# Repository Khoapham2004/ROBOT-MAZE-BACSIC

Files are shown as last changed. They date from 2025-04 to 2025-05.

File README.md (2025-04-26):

# ROBOT-MAZE-BACSIC
design in kicad : 
Arduino nano, HC-SR04, N20, Driver TB6612FNG, MPU, LM2596, Botton

 




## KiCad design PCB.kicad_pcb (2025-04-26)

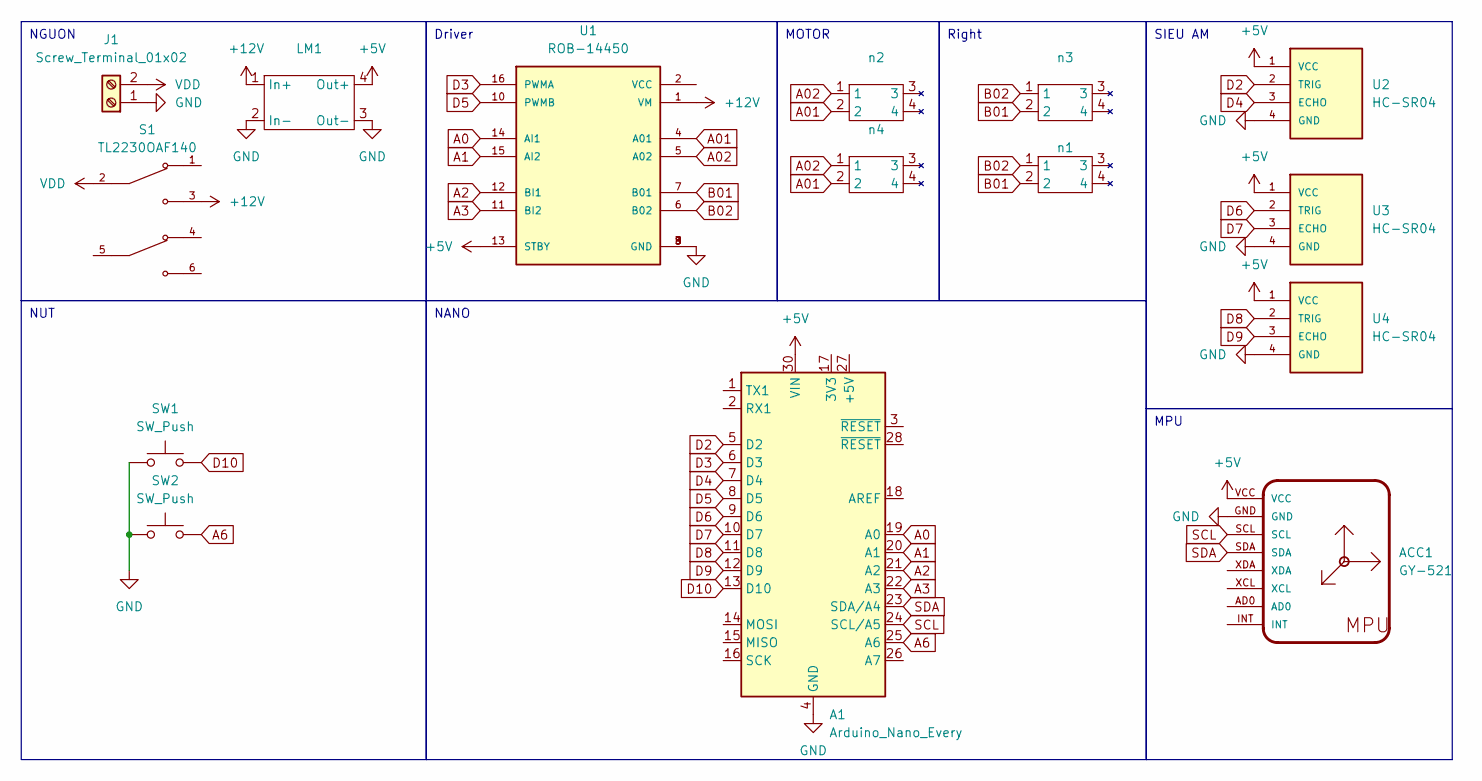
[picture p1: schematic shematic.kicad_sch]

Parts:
A1: Arduino_Nano_Every; Arduino_Nano
ACC1: GY-521
J1: Screw_Terminal_01x02; TerminalBlock_Phoenix_MKDS-1,5-2_1x02_P5.00mm_Horizontal
LM1: Lm2596
S1: TL2230OAF140; SW_6 pins 8.5×8.5MM; PARTREV E
SW1, SW2: SW_Push; SW_PUSH_6mm_H9.5mm
U1: ROB-14450; MODULE_ROB-14450; PARTREV 11-13-17
U2, U3, U4: HC-SR04; XCVR_HC-SR04
n1, n2, n3, n4: n20

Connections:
+5V: A1.30 (VIN), ACC1.VCC, LM1.4 (Out+), U1.13 (STBY), U2.1 (VCC), U3.1 (VCC), U4.1 (VCC)
+12V: LM1.1 (In+), S1.3, U1.1 (VM)
A0: A1.19 (A0), U1.14 (AI1)
A1: A1.20 (A1), U1.15 (AI2)
A01: U1.4 (A01), n2.2, n4.2
A2: A1.21 (A2), U1.12 (BI1)
A02: U1.5 (A02), n2.1, n4.1
A3: A1.22 (A3), U1.11 (BI2)
A6: A1.25 (A6), SW2.2
B01: U1.7 (B01), n1.2, n3.2
B02: U1.6 (B02), n1.1, n3.1
D2: A1.5 (D2), U2.2 (TRIG)
D3: A1.6 (D3), U1.16 (PWMA)
D4: A1.7 (D4), U2.3 (ECHO)
D5: A1.8 (D5), U1.10 (PWMB)
D6: A1.9 (D6), U3.2 (TRIG)
D7: A1.10 (D7), U3.3 (ECHO)
D8: A1.11 (D8), U4.2 (TRIG)
D9: A1.12 (D9), U4.3 (ECHO)
D10: A1.13 (D10), SW1.2
GND: A1.4 (GND), A1.29 (GND), ACC1.GND, J1.1, LM1.2 (In-), LM1.3 (Out-), SW1.1, SW2.1, U1.3 (GND), U1.8 (GND), U1.9 (GND), U2.4 (GND), U3.4 (GND), U4.4 (GND)
SCL: A1.24 (SCL/A5), ACC1.SCL
SDA: A1.23 (SDA/A4), ACC1.SDA
VDD: J1.2, S1.2

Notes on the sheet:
NGUON
NUT
SIEU AM
MPU
Right
NANO
MOTOR
Driver

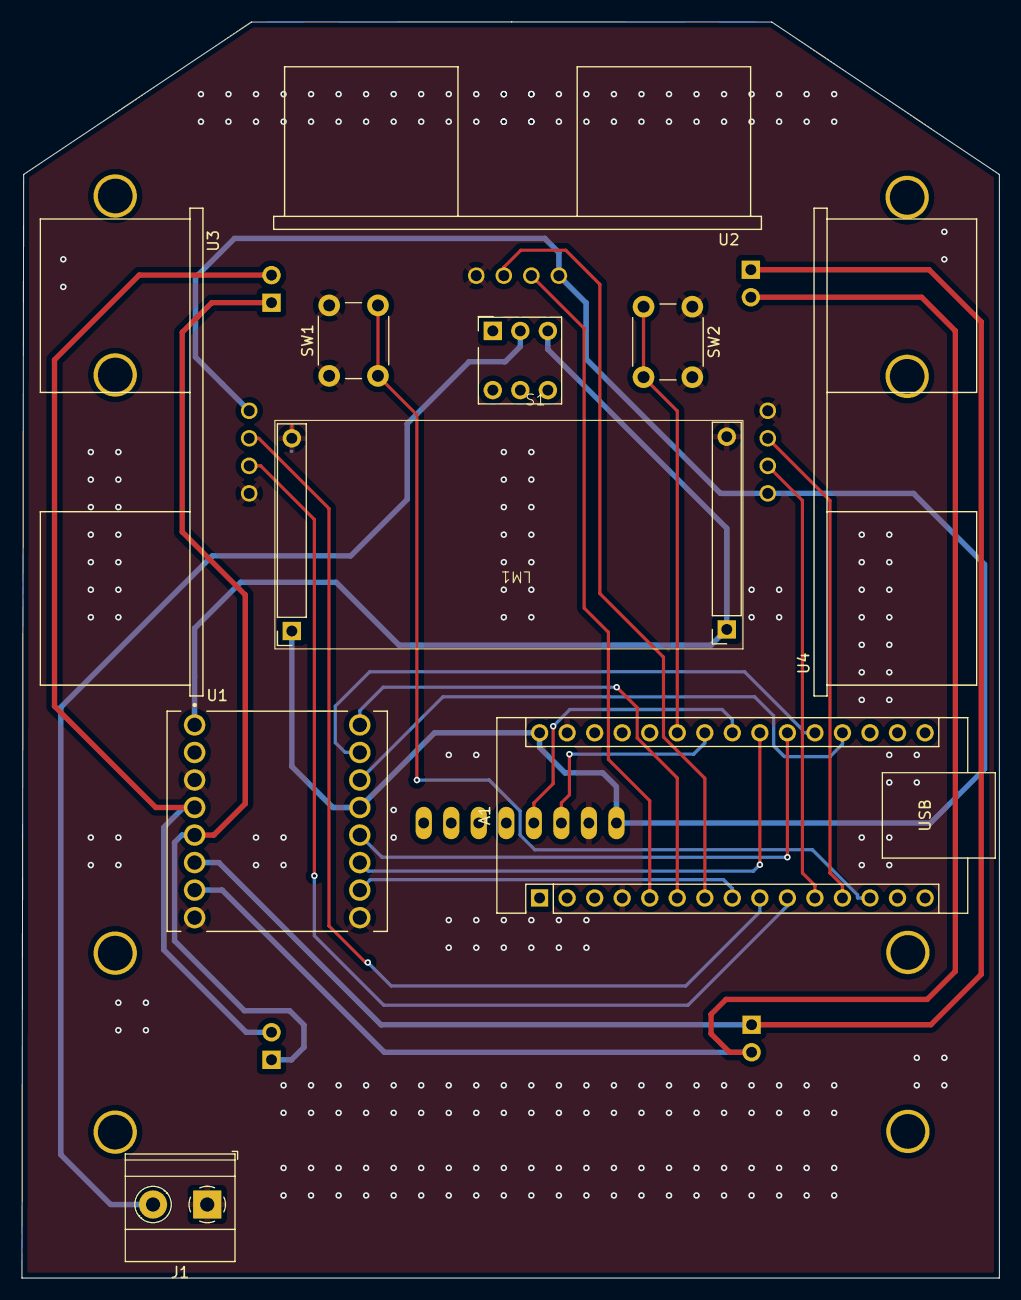
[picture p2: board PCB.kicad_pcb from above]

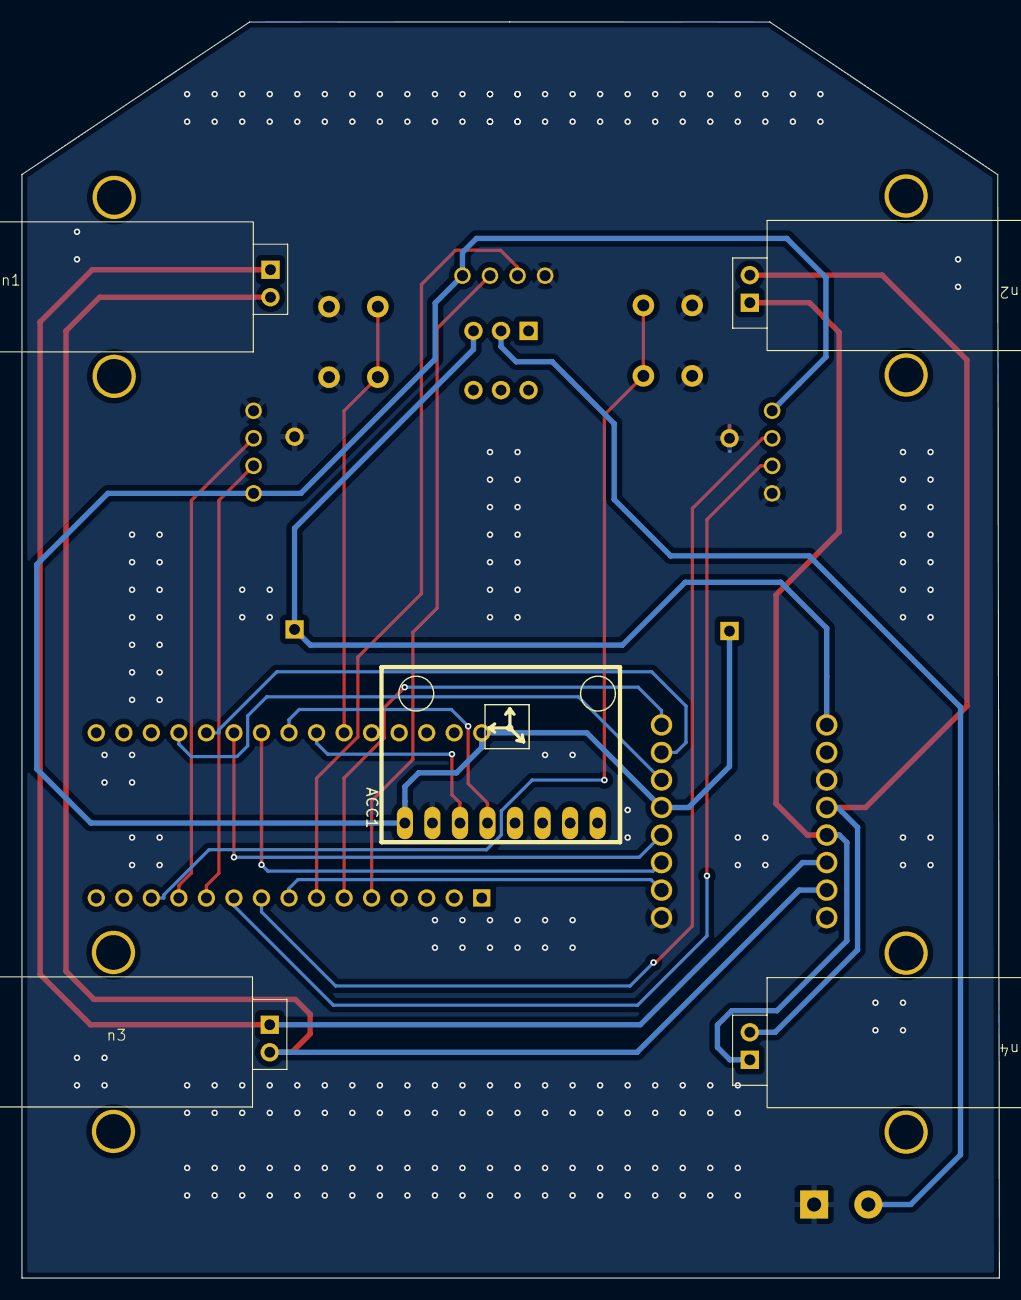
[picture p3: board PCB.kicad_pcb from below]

Board: 2 copper layers, 90.2 x 115.9 mm, 15 parts (5 on the bottom side), 24 nets.

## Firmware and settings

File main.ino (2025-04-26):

#include <Wire.h>
#include <MPU6050.h>

MPU6050 mpu;

// Cảm biến siêu âm
int trig1 = 6, echo1 = 7;
int trig2 = 2, echo2 = 4;
int trig3 = 8, echo3 = 9;

#define buttonR 10
#define buttonL A6
// Motor driver
#define AIN1 A0
#define AIN2 A1
#define PWMA 3
#define BIN1 A2
#define BIN2 A3
#define PWMB 5

// Ngưỡng & tốc độ
float speedSound = 0.0343;
int DIS = 15;
int speed = 100;

// Khoảng cách đo được
long leftDistance, middleDistance, rightDistance;

// Biến yaw
float yaw = 0;
unsigned long lastTime;

// Đọc khoảng cách siêu âm
long measureDistance(int trig, int echo) {
  digitalWrite(trig, LOW);
  delayMicroseconds(2);
  digitalWrite(trig, HIGH);
  delayMicroseconds(10);
  digitalWrite(trig, LOW);
  return (pulseIn(echo, HIGH) / 2.0) * speedSound;
}

// Cập nhật yaw bằng tích phân gyroZ
void updateYaw() {
  int16_t gx, gy, gz, ax, ay, az;
  mpu.getMotion6(&ax, &ay, &az, &gx, &gy, &gz);
  unsigned long now = millis();
  float dt = (now - lastTime) / 1000.0;
  lastTime = now;
  float gyroZ = gz / 131.0;      // độ/giây
  yaw += gyroZ * dt;            // tích phân thành góc
}

// Quay trái chính xác 90°
void turnLeft90() {
  updateYaw();
  float start = yaw;
  // bắt đầu quay trái
  digitalWrite(AIN1, LOW); digitalWrite(AIN2, HIGH);
  digitalWrite(BIN1, LOW); digitalWrite(BIN2, HIGH);
  analogWrite(PWMA, speed);
  analogWrite(PWMB, speed);
  // quay cho đến khi đạt ~90°
  while (abs(yaw - start) < 85) {
    updateYaw();
  }
  // dừng
  analogWrite(PWMA, 0);
  analogWrite(PWMB, 0);
  delay(200);
}

// Quay phải chính xác 90°
void turnRight90() {
  updateYaw();
  float start = yaw;
  // bắt đầu quay phải
  digitalWrite(AIN1, HIGH); digitalWrite(AIN2, LOW);
  digitalWrite(BIN1, HIGH); digitalWrite(BIN2, LOW);
  analogWrite(PWMA, speed);
  analogWrite(PWMB, speed);
  // quay cho đến khi đạt ~90°
  while (abs(yaw - start) < 85) {
    updateYaw();
  }
  // dừng
  analogWrite(PWMA, 0);
  analogWrite(PWMB, 0);
  delay(200);
}
// Quay phải chính xác 90°
void turnRight180() {
  updateYaw();
  float start = yaw;
  // bắt đầu quay phải
  digitalWrite(AIN1, HIGH); digitalWrite(AIN2, LOW);
  digitalWrite(BIN1, HIGH); digitalWrite(BIN2, LOW);
  analogWrite(PWMA, speed);
  analogWrite(PWMB, speed);
  // quay cho đến khi đạt ~90°
  while (abs(yaw - start) < 180) {
    updateYaw();
  }
  // dừng
  analogWrite(PWMA, 0);
  analogWrite(PWMB, 0);
  delay(200);
}

// Di chuyển tiến thẳng
void moveForward() {
  digitalWrite(AIN1, HIGH); digitalWrite(AIN2, LOW);
  digitalWrite(BIN1, LOW);  digitalWrite(BIN2, HIGH);
  analogWrite(PWMA, speed);
  analogWrite(PWMB, speed);
}

// Dừng
void moveStop() {
  digitalWrite(AIN1, LOW); digitalWrite(AIN2, LOW);
  digitalWrite(BIN1, LOW); digitalWrite(BIN2, LOW);
  analogWrite(PWMA, 0);
  analogWrite(PWMB, 0);
}

// Điều chỉnh song song tường phải
void moveForwardR() {
  long r = measureDistance(trig3, echo3);
  if (r < 6)        analogWrite(PWMB, speed), analogWrite(PWMA, speed/2);
  else if (r > 7)   analogWrite(PWMA, speed), analogWrite(PWMB, speed/2);
  else              analogWrite(PWMA, speed), analogWrite(PWMB, speed);
  digitalWrite(AIN1, HIGH); digitalWrite(AIN2, LOW);
  digitalWrite(BIN1, LOW);  digitalWrite(BIN2, HIGH);
}

// Điều chỉnh song song tường trái
void moveForwardL() {
  long l = measureDistance(trig1, echo1);
  if (l < 7)        analogWrite(PWMB, speed/2), analogWrite(PWMA, speed);
  else if (l > 8)   analogWrite(PWMA, speed/2), analogWrite(PWMB, speed);
  else              analogWrite(PWMA, speed),   analogWrite(PWMB, speed);
  digitalWrite(AIN1, HIGH); digitalWrite(AIN2, LOW);
  digitalWrite(BIN1, LOW);  digitalWrite(BIN2, HIGH);
}

void setup() {
  Serial.begin(9600);
  Wire.begin();
  mpu.initialize();
  if (!mpu.testConnection()) {
    Serial.println("MPU6050 lỗi kết nối!");
    while (1);
  }
  lastTime = millis();
  yaw = 0; // reset góc ban đầu
  pinMode(buttonR, INPUT_PULLUP);   // Chân D10 dùng kéo trở trong
  pinMode(buttonL, INPUT_PULLUP);    // Chân A6 cũng dùng kéo trở trong
  // khởi tạo siêu âm
  pinMode(trig1, OUTPUT); pinMode(echo1, INPUT);
  pinMode(trig2, OUTPUT); pinMode(echo2, INPUT);
  pinMode(trig3, OUTPUT); pinMode(echo3, INPUT);

  // khởi tạo motor
  pinMode(AIN1, OUTPUT); pinMode(AIN2, OUTPUT); pinMode(PWMA, OUTPUT);
  pinMode(BIN1, OUTPUT); pinMode(BIN2, OUTPUT); pinMode(PWMB, OUTPUT);

  moveStop();
}

void loop() {
  moveStop();
  delay(10);

  // Chờ 2 cảm biến trái+phải <20 mới bắt đầu
  while (true) {
    leftDistance  = measureDistance(trig1, echo1);
    rightDistance = measureDistance(trig3, echo3);
    if (leftDistance < 25 && rightDistance < 25) break;
    delay(200);
  }

  // Vòng chạy chính
  while (true) {
    // cập nhật yaw liên tục
    updateYaw();

    // đo khoảng cách
    leftDistance   = measureDistance(trig1, echo1);    delay(10);
    middleDistance = measureDistance(trig2, echo2);    delay(10);
    rightDistance  = measureDistance(trig3, echo3);    delay(10);

    Serial.print("L:"); Serial.print(leftDistance);
    Serial.print(" M:"); Serial.print(middleDistance);
    Serial.print(" R:"); Serial.println(rightDistance);

    if (leftDistance < DIS && middleDistance > DIS && rightDistance < DIS) {
      // đi thẳng + tự chỉnh                               
      moveForward();
      if (leftDistance < rightDistance && leftDistance < 8) {
        analogWrite(PWMA, 100); analogWrite(PWMB, 80);
      } else if (rightDistance < leftDistance && rightDistance < 8) {
        analogWrite(PWMA, 80); analogWrite(PWMB, 100);
      }
    }
    else if (leftDistance > DIS && middleDistance > DIS && rightDistance < DIS) {
      moveForwardR();
    }
    else if (leftDistance < DIS && middleDistance > DIS && rightDistance > DIS) {
      moveForwardL();
    }
    else if (leftDistance > DIS && middleDistance < DIS && rightDistance > DIS) {
      // quẹo phải 90°
      moveForward(); delay(300);
      moveStop();    delay(200);
      turnRight90();
      moveForward();
    }
    else if (leftDistance > DIS && middleDistance < DIS && rightDistance < DIS) {
      // quẹo trái 90°
      moveForward(); delay(300);
      moveStop();    delay(200);
      turnLeft90();
      moveForward();
    }
    else if (leftDistance < DIS && middleDistance < DIS && rightDistance > DIS) {
      // quẹo phải 90°
      moveForward(); delay(300);
      moveStop();    delay(200);
      turnRight90();
      moveForward();
    }
    else if (leftDistance < DIS && middleDistance < DIS && rightDistance < DIS) {
      // chặn 3 phía → dừng và quẹo trái 90°
      moveStop();
      turnRight180();
    }

    delay(10);
  }
}

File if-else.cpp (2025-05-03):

#include <Wire.h>
#include <MPU6050.h>

MPU6050 mpu;
bool justTurned180 = false;

// Cảm biến siêu âm
int trig1 = 6, echo1 = 7; 
int trig2 = 2, echo2 = 4;
int trig3 = 8, echo3 = 9;

#define BTN_LEFT 10  // D10: nút chọn bám trái
#define BTN_RIGHT A6   // A6: nút chọn bám phải
int mode = 0;         // 0: chưa chọn, 1: bám trái, 2: bám phải

// Motor driver
#define AIN1 A0
#define AIN2 A1
#define PWMA 3
#define BIN1 A2
#define BIN2 A3
#define PWMB 5

float speedSound = 0.0343;
int DIS = 10;///////////////////////////
int speed = 100;////////////////////////

long leftDistance, middleDistance, rightDistance;
float yaw = 0;
unsigned long lastTime;

// Đọc khoảng cách
long measureDistance(int trig, int echo) {
  digitalWrite(trig, LOW);
  delayMicroseconds(2);
  digitalWrite(trig, HIGH);
  delayMicroseconds(10);
  digitalWrite(trig, LOW);
  return (pulseIn(echo, HIGH) / 2.0) * speedSound;
}
// Dừng
void moveStop() {
  digitalWrite(AIN1, LOW); digitalWrite(AIN2, LOW);
  digitalWrite(BIN1, LOW); digitalWrite(BIN2, LOW);
  analogWrite(PWMA, 0); analogWrite(PWMB, 0);
}
// Cập nhật góc
void updateYaw() {
  int16_t gx, gy, gz, ax, ay, az;
  mpu.getMotion6(&ax, &ay, &az, &gx, &gy, &gz);
  unsigned long now = millis();
  float dt = (now - lastTime) / 1000.0;
  lastTime = now;
  yaw += (gz / 131.0) * dt;
}

// Quay trái 90°
void turnLeft90() {
  updateYaw();
  float start = yaw;
  digitalWrite(AIN1, HIGH); digitalWrite(AIN2, LOW);
  digitalWrite(BIN1, LOW);  digitalWrite(BIN2, HIGH);
  analogWrite(PWMA, speed);
  analogWrite(PWMB, speed);
  while (abs(yaw - start) < 80) updateYaw();//////////////////////////////
  moveStop(); delay(200);
}

// Quay phải 90°
void turnRight90() {
  updateYaw();
  float start = yaw;
  digitalWrite(AIN1, LOW); digitalWrite(AIN2, HIGH);
  digitalWrite(BIN1, HIGH); digitalWrite(BIN2, LOW);
  analogWrite(PWMA, speed);
  analogWrite(PWMB, speed);
  while (abs(yaw - start) < 80) updateYaw();////////////////////////////////
  moveStop(); delay(200);
}
// Quay phải 90°
void turnRight180() {
  updateYaw();
  float start = yaw;
  digitalWrite(AIN1, LOW); digitalWrite(AIN2, HIGH);
  digitalWrite(BIN1, HIGH); digitalWrite(BIN2, LOW);
  analogWrite(PWMA, speed);
  analogWrite(PWMB, speed);
  while (abs(yaw - start) < 170) updateYaw();////////////////////////////////
  moveStop(); delay(200);
}

// Di chuyển thẳng
void moveForward() {
  digitalWrite(AIN1, LOW); digitalWrite(AIN2, HIGH);
  analogWrite(PWMA, speed);
  digitalWrite(BIN1, LOW); digitalWrite(BIN2, HIGH);
  analogWrite(PWMB, speed);
}

// Bám tường phải
void moveForwardR() {
long r = measureDistance(trig3, echo3);
if (r < 7) {
  analogWrite(PWMA, speed / 2); analogWrite(PWMB, speed);
} else if (r > 8) {
  analogWrite(PWMA, speed); analogWrite(PWMB, speed / 2);
} else {
  analogWrite(PWMA, speed); analogWrite(PWMB, speed);
}
digitalWrite(AIN1, LOW); digitalWrite(AIN2, HIGH);
digitalWrite(BIN1, LOW); digitalWrite(BIN2, HIGH);
}

// Bám tường trái
void moveForwardL() {
long l = measureDistance(trig1, echo1);
if (l < 7) {
  analogWrite(PWMA, speed); analogWrite(PWMB, speed / 2);
} else if (l > 8) {
  analogWrite(PWMA, speed / 2); analogWrite(PWMB, speed);
} else {
  analogWrite(PWMA, speed); analogWrite(PWMB, speed);
}
digitalWrite(AIN1, LOW); digitalWrite(AIN2, HIGH);
digitalWrite(BIN1, LOW); digitalWrite(BIN2, HIGH);
}

void setup() {
Serial.begin(9600);
Wire.begin();
mpu.initialize();
if (!mpu.testConnection()) {
  Serial.println("MPU6050 lỗi kết nối!");
  while (1);
}
lastTime = millis();
yaw = 0;

pinMode(BTN_RIGHT, INPUT_PULLUP);
pinMode(BTN_LEFT, INPUT_PULLUP);

pinMode(trig1, OUTPUT); pinMode(echo1, INPUT);
pinMode(trig2, OUTPUT); pinMode(echo2, INPUT);
pinMode(trig3, OUTPUT); pinMode(echo3, INPUT);

pinMode(AIN1, OUTPUT); pinMode(AIN2, OUTPUT); pinMode(PWMA, OUTPUT);
pinMode(BIN1, OUTPUT); pinMode(BIN2, OUTPUT); pinMode(PWMB, OUTPUT);

moveStop();
Serial.println(">> ĐANG CHỜ CHỌN HƯỚNG BÁM...");
}

void loop() {

while (mode == 0) {
if (digitalRead(BTN_LEFT) == LOW) {
  mode = 1;  // bám trái
  Serial.println(">> Đã chọn: BÁM TRÁI");
  delay(500);
} else if (analogRead(BTN_RIGHT) < 255/2) {
  // giá trị < ~300 khi nhấn nếu dùng trở kéo xuống đất
  mode = 2;  // bám phải
  Serial.println(">> Đã chọn: BÁM PHẢI");
  delay(500);
}
}


// Chờ phát hiện tường 2 bên
Serial.println(">> ĐÃ CHỌN – CHỜ TƯỜNG 2 BÊN...");
while (true) {
  leftDistance = measureDistance(trig1, echo1);
  rightDistance = measureDistance(trig3, echo3);
  if (leftDistance < 25 && rightDistance < 25) break;
  delay(200);
}

Serial.println(">> BẮT ĐẦU DI CHUYỂN!");

// Vòng điều khiển chính
while (true) {
  updateYaw();

  leftDistance = measureDistance(trig1, echo1);
  delay(10);
  middleDistance = measureDistance(trig2, echo2);
  delay(10);
  rightDistance = measureDistance(trig3, echo3);
  delay(10);
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

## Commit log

2025-04-26 Update and rename ducanhne.kicad_sch to shematic.kicad_sch
    [shematic.kicad_sch]
2025-04-26 Update and rename ducanhne.kicad_pcb to PCB.kicad_pcb
    [PCB.kicad_pcb]
